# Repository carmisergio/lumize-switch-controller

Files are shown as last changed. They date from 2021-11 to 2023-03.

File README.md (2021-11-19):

# Lumize Switch Controller

A rack-mountable device for receiving input from physical wall switches and using it in a home automation situation

## Goal

When designing the home automation system for a reasonably sized attic, I came to the conclusion
that there aren't any good commercial solutions for reliably reading button input from switches mounted
in regular wall boxes. So I decided to design my own.

To avoid the complication (and waste of space) of having a network connected microcontroller in
each wall box, I chose to implement a solution based on a central device, with cables running to each button.
This poses the challenge of bringing upwards of four signals all the way from each corner of the floor
to a central location. The only cheap and easy to come by cable that has enough conductors is UTP cable,
usually used for ethernet networks. The cable is terminated as RJ45 male inside the wall box, and into a
patch panel at the central location.

## Switches

For my system, I wanted to use regular italian style wall switches, so I needed a way of interfacing
the RJ45 to some bare wire to be plugged into the buttons. This is done with a simple PCB i call the
"Switch Terminator Board", which exposes the connections as screw terminals.

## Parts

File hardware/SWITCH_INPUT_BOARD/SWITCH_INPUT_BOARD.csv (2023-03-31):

Source: | /home/sergio/projects/lumize-switch-controller/hardware/SWITCH_INPUT_BOARD/SWITCH_INPUT_BOARD.sch
Date: | Sun 13 Mar 2022 12:25:39 PM CET
Tool: | Eeschema (6.0.2)
Generator: | /usr/share/kicad/plugins/bom_csv_grouped_by_value_with_fp.py
Component Count: | 24
Ref | Qnty | Value | Cmp name | Footprint | Description | Vendor
C1, | 1 | 10uF | CP | Capacitor_THT:CP_Radial_D4.0mm_P1.50mm
D1, | 1 | LED | LED | LED_SMD:LED_0805_2012Metric | Light emitting diode
J1, | 1 | 4 Port RJ45: A00-432-262-450 | A00-432-262-450-A00-432-262-450 | A00-432-262-450:A00-432-262-450
J2, J3, J4, | 3 | IDC_02x04 | Conn_02x04_Odd_Even | Connector_IDC:IDC-Header_2x04_P2.54mm_Vertical | Generic connector, double row, 02x04, odd/even pin numbering scheme (row 1 odd numbers, row 2 even numbers), script generated (kicad-library-utils/schlib/autogen/connector/)
J5, | 1 | IDC_02x06 | Conn_02x06_Odd_Even | Connector_IDC:IDC-Header_2x06_P2.54mm_Vertical | Generic connector, double row, 02x06, odd/even pin numbering scheme (row 1 odd numbers, row 2 even numbers), script generated (kicad-library-utils/schlib/autogen/connector/)
JP1, | 1 | Jumper_4X | Jumper_4X | Connector_PinHeader_2.54mm:PinHeader_2x04_P2.54mm_Vertical
JP2, JP3, JP4, | 3 | Jumper_2X | Jumper_2X | Connector_PinHeader_2.54mm:PinHeader_2x02_P2.54mm_Vertical
R1, R2, | 2 | 4.7K | R | Resistor_THT:R_Axial_DIN0207_L6.3mm_D2.5mm_P10.16mm_Horizontal | Resistor
R3, | 1 | 220 | R | Resistor_THT:R_Axial_DIN0207_L6.3mm_D2.5mm_P10.16mm_Horizontal | Resistor
RN1, RN2, RN3, RN4, | 4 | 4x1K | R_Pack04 | Resistor_SMD:R_Array_Convex_4x1206 | 4 resistor network, parallel topology
RN5, RN6, RN7, RN8, RN9, | 5 | 4x10K | R_Pack04 | Resistor_SMD:R_Array_Convex_4x1206 | 4 resistor network, parallel topology
U1, | 1 | MCP23017_SO | MCP23017_SO | Package_SO:SOIC-28W_7.5x17.9mm_P1.27mm | 16-bit I/O expander, I2C, interrupts, w pull-ups, SOIC-28

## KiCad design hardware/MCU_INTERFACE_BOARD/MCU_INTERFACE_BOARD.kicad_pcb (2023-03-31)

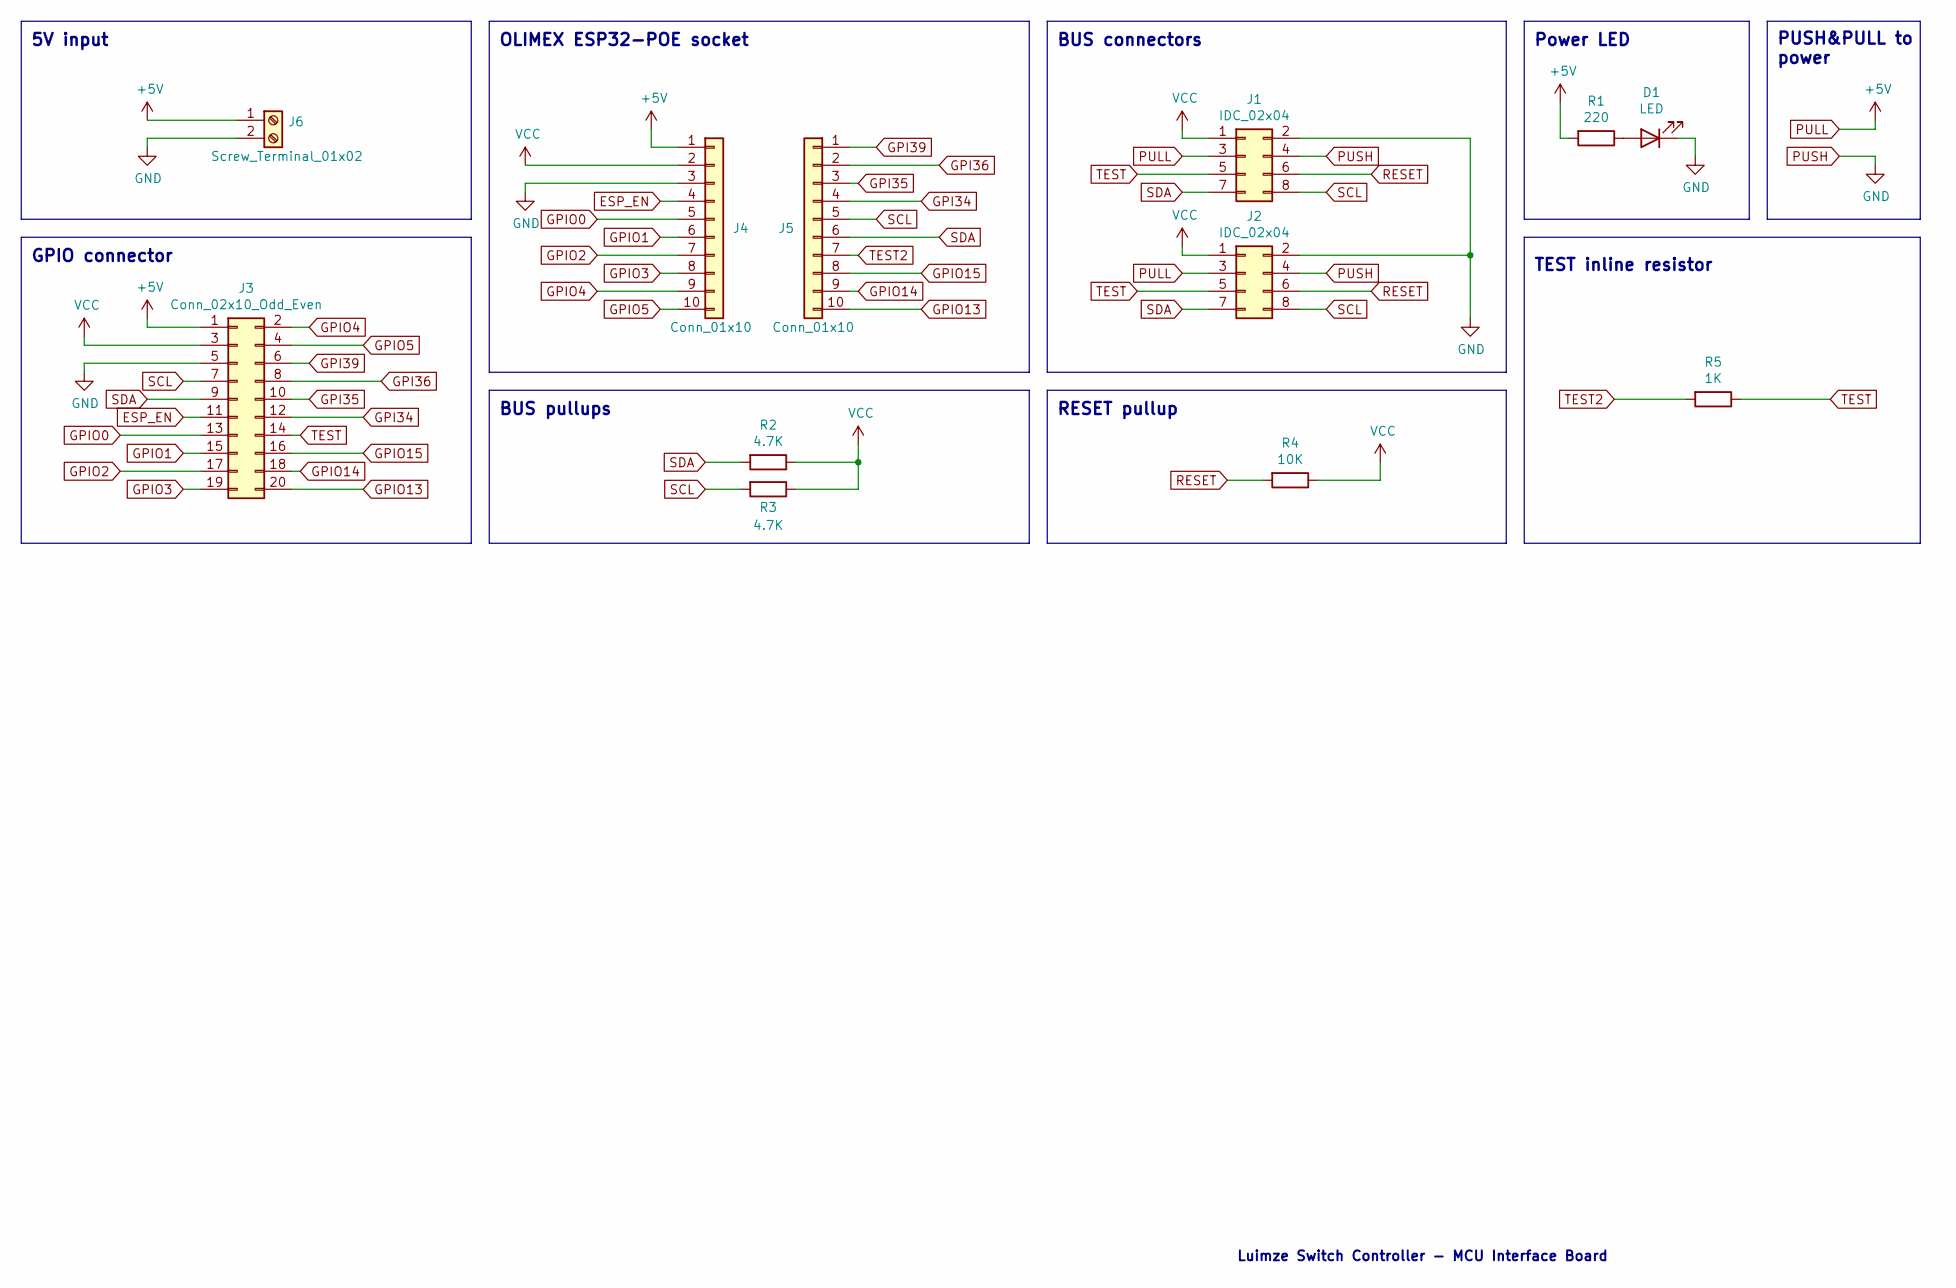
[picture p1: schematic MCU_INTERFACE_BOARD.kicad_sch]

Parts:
D1: LED; LED_0805_2012Metric
J1, J2: IDC_02x04; IDC-Header_2x04_P2.54mm_Vertical
J3: Conn_02x10_Odd_Even; IDC-Header_2x10_P2.54mm_Vertical
J4, J5: Conn_01x10; PinHeader_1x10_P2.54mm_Vertical
J6: Screw_Terminal_01x02; TerminalBlock_4Ucon_1x02_P3.50mm_Horizontal
R1: 220; R_Axial_DIN0207_L6.3mm_D2.5mm_P10.16mm_Horizontal
R2, R3: 4.7K; R_Axial_DIN0207_L6.3mm_D2.5mm_P10.16mm_Horizontal
R4: 10K; R_Axial_DIN0207_L6.3mm_D2.5mm_P10.16mm_Horizontal
R5: 1K; R_Axial_DIN0207_L6.3mm_D2.5mm_P10.16mm_Horizontal

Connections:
ESP_EN: J3.11, J4.4
GPI34: J3.12, J5.4
GPI35: J3.10, J5.3
GPI36: J3.8, J5.2
GPI39: J3.6, J5.1
GPIO0: J3.13, J4.5
GPIO1: J3.15, J4.6
GPIO2: J3.17, J4.7
GPIO3: J3.19, J4.8
GPIO4: J3.2, J4.9
GPIO5: J3.4, J4.10
GPIO13: J3.20, J5.10
GPIO14: J3.18, J5.9
GPIO15: J3.16, J5.8
unnamed: D1.2 (A), R1.1
PULL: J1.3, J2.3, J3.1, J4.1, J6.1, R1.2
PUSH: D1.1 (K), J1.2, J1.4, J2.2, J2.4, J3.5, J4.3, J6.2
RESET: J1.6, J2.6, R4.2
SCL: J1.8, J2.8, J3.7, J5.5, R3.2
SDA: J1.7, J2.7, J3.9, J5.6, R2.2
TEST: J1.5, J2.5, J3.14, R5.1
TEST2: J5.7, R5.2
VCC: J1.1, J2.1, J3.3, J4.2, R2.1, R3.1, R4.1

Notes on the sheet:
TEST inline resistor
BUS pullups
OLIMEX ESP32-POE socket
PUSH&PULL to power
GPIO connector
BUS connectors
Luimze Switch Controller - MCU Interface Board
5V input
Power LED
RESET pullup

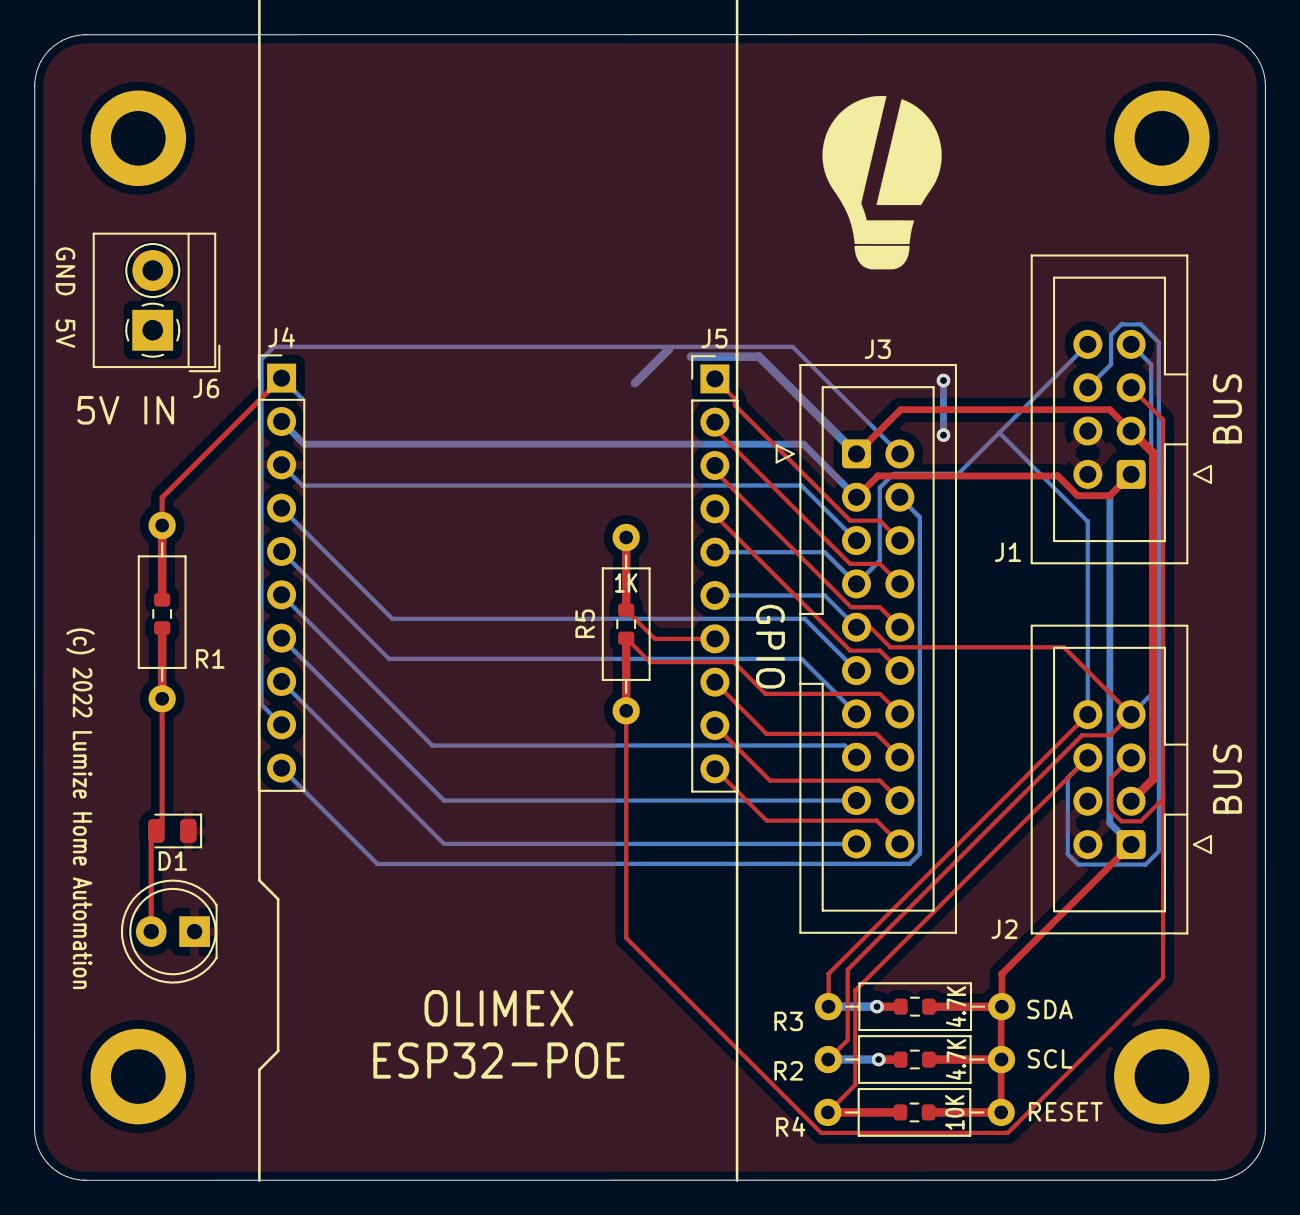
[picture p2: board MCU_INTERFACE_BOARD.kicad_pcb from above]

Board: 2 copper layers, 72.2 x 67.2 mm, 12 parts (0 on the bottom side), 23 nets.

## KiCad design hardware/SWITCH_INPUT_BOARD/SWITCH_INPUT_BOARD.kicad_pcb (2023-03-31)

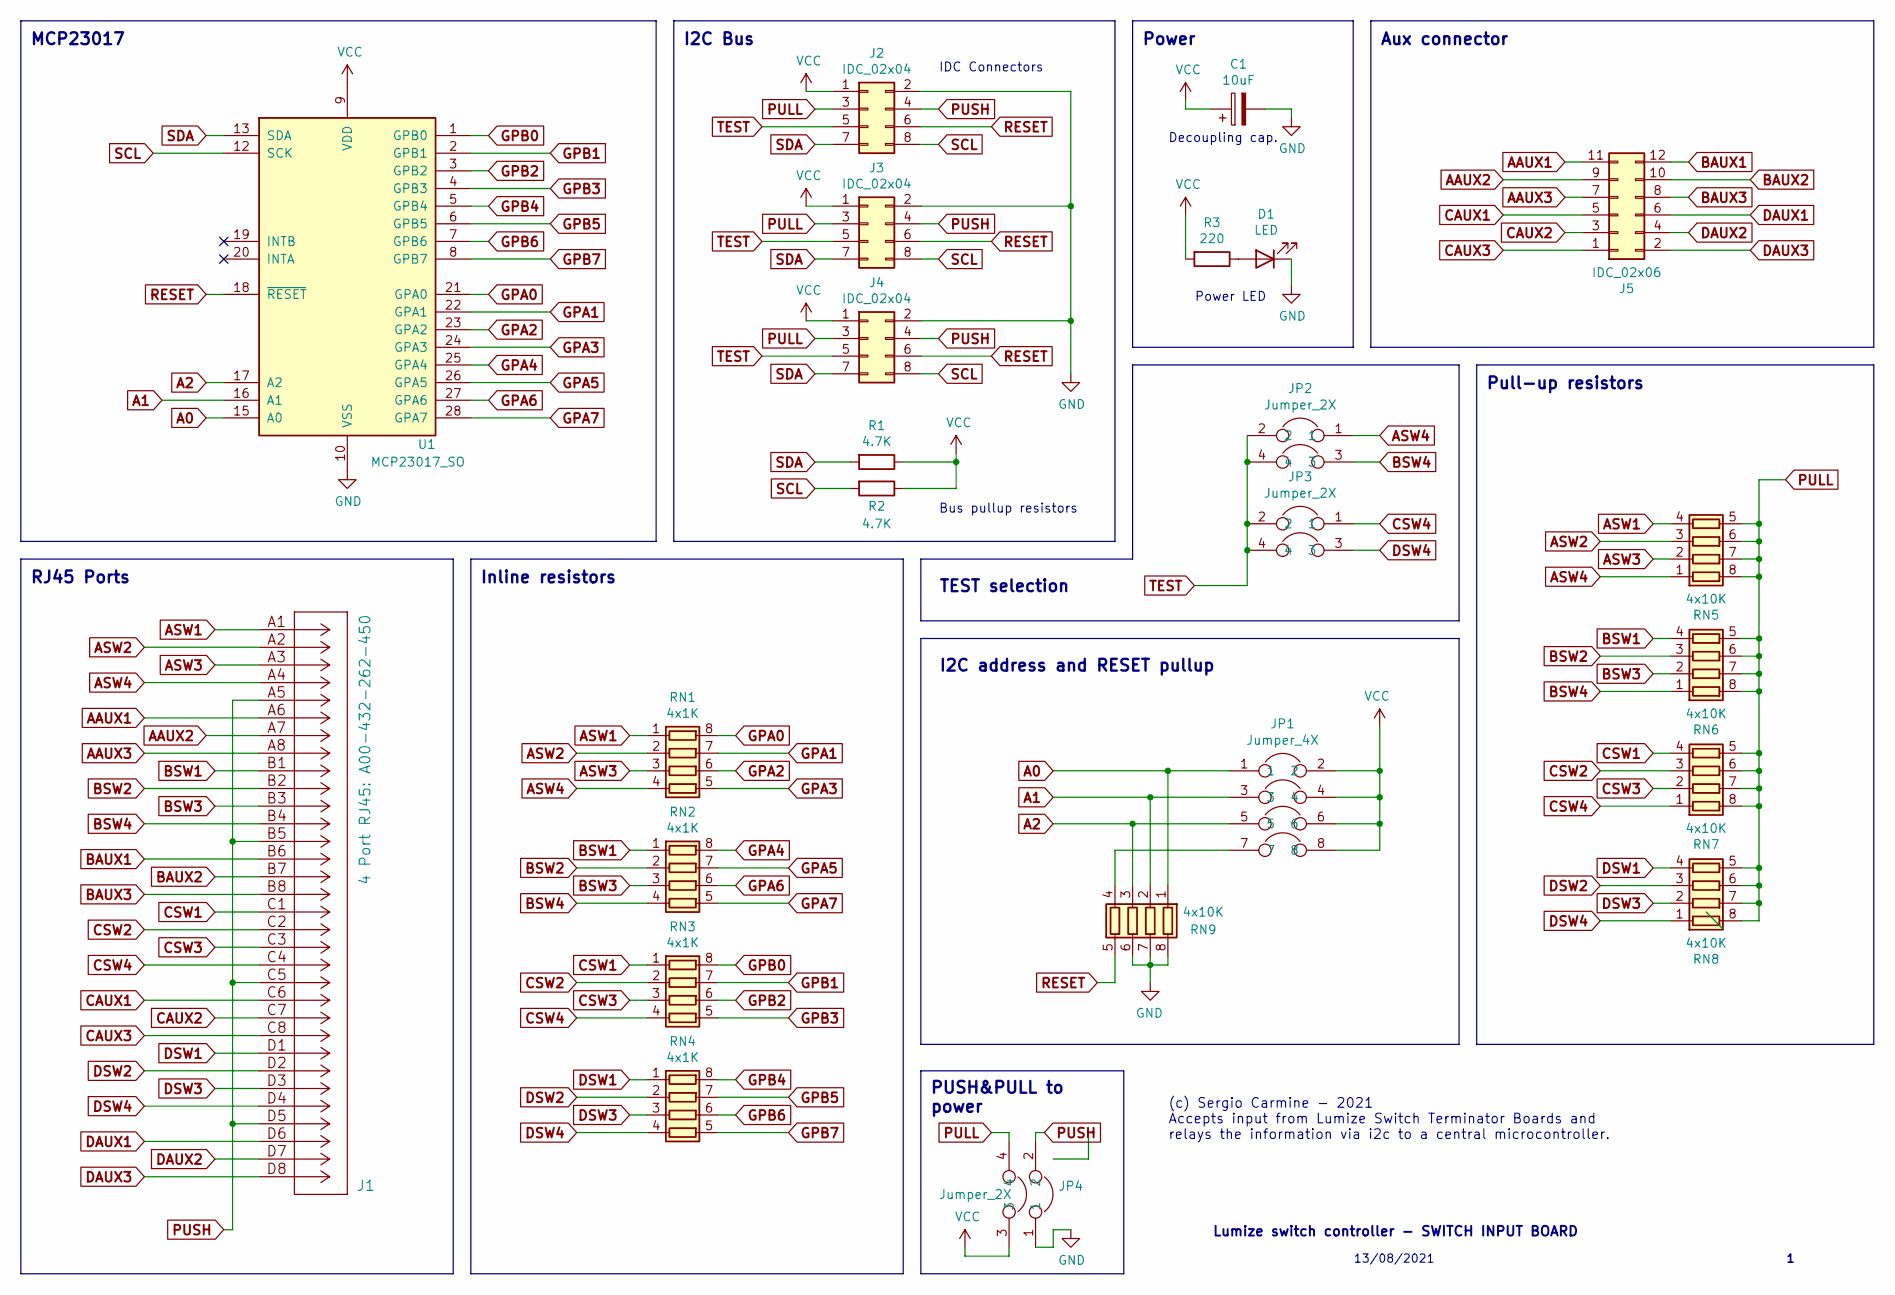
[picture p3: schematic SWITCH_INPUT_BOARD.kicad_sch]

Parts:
C1: 10uF; CP_Radial_D4.0mm_P1.50mm
D1: LED; LED_0805_2012Metric
J1: 4 Port RJ45: A00-432-262-450; A00-432-262-450
J2, J3, J4: IDC_02x04; IDC-Header_2x04_P2.54mm_Vertical
J5: IDC_02x06; IDC-Header_2x06_P2.54mm_Vertical
JP1: Jumper_4X; PinHeader_2x04_P2.54mm_Vertical
JP2, JP3, JP4: Jumper_2X; PinHeader_2x02_P2.54mm_Vertical
R1, R2: 4.7K; R_Axial_DIN0207_L6.3mm_D2.5mm_P10.16mm_Horizontal
R3: 220; R_Axial_DIN0207_L6.3mm_D2.5mm_P10.16mm_Horizontal
RN1, RN2, RN3, RN4: 4x1K; R_Array_Convex_4x1206
RN5, RN6, RN7, RN8, RN9: 4x10K; R_Array_Convex_4x1206
U1: MCP23017_SO; SOIC-28W_7.5x17.9mm_P1.27mm

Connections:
A0: JP1.1, RN9.1 (R1.1), U1.15 (A0)
A1: JP1.3, RN9.2 (R2.1), U1.16 (A1)
A2: JP1.5, RN9.3 (R3.1), U1.17 (A2)
AAUX1: J1.A6, J5.11
AAUX2: J1.A7, J5.9
AAUX3: J1.A8, J5.7
ASW1: J1.A1, RN1.1 (R1.1), RN5.4 (R4.1)
ASW2: J1.A2, RN1.2 (R2.1), RN5.3 (R3.1)
ASW3: J1.A3, RN1.3 (R3.1), RN5.2 (R2.1)
ASW4: J1.A4, JP2.1, RN1.4 (R4.1), RN5.1 (R1.1)
BAUX1: J1.B6, J5.12
BAUX2: J1.B7, J5.10
BAUX3: J1.B8, J5.8
BSW1: J1.B1, RN2.1 (R1.1), RN6.4 (R4.1)
BSW2: J1.B2, RN2.2 (R2.1), RN6.3 (R3.1)
BSW3: J1.B3, RN2.3 (R3.1), RN6.2 (R2.1)
BSW4: J1.B4, JP2.3, RN2.4 (R4.1), RN6.1 (R1.1)
CAUX1: J1.C6, J5.5
CAUX2: J1.C7, J5.3
CAUX3: J1.C8, J5.1
CSW1: J1.C1, RN3.1 (R1.1), RN7.4 (R4.1)
CSW2: J1.C2, RN3.2 (R2.1), RN7.3 (R3.1)
CSW3: J1.C3, RN3.3 (R3.1), RN7.2 (R2.1)
CSW4: J1.C4, JP3.1, RN3.4 (R4.1), RN7.1 (R1.1)
DAUX1: J1.D6, J5.6
DAUX2: J1.D7, J5.4
DAUX3: J1.D8, J5.2
DSW1: J1.D1, RN4.1 (R1.1), RN8.4 (R4.1)
DSW2: J1.D2, RN4.2 (R2.1), RN8.3 (R3.1)
DSW3: J1.D3, RN4.3 (R3.1), RN8.2 (R2.1)
DSW4: J1.D4, JP3.3, RN4.4 (R4.1), RN8.1 (R1.1)
GND: C1.2, D1.1 (K), J2.2, J3.2, J4.2, JP4.1, RN9.6 (R3.2), RN9.7 (R2.2), RN9.8 (R1.2), U1.10 (VSS); also elsewhere on the board
GPA0: RN1.8 (R1.2), U1.21 (GPA0)
GPA1: RN1.7 (R2.2), U1.22 (GPA1)
GPA2: RN1.6 (R3.2), U1.23 (GPA2)
GPA3: RN1.5 (R4.2), U1.24 (GPA3)
GPA4: RN2.8 (R1.2), U1.25 (GPA4)
GPA5: RN2.7 (R2.2), U1.26 (GPA5)
GPA6: RN2.6 (R3.2), U1.27 (GPA6)
GPA7: RN2.5 (R4.2), U1.28 (GPA7)
GPB0: RN3.8 (R1.2), U1.1 (GPB0)
GPB1: RN3.7 (R2.2), U1.2 (GPB1)
GPB2: RN3.6 (R3.2), U1.3 (GPB2)
GPB3: RN3.5 (R4.2), U1.4 (GPB3)
GPB4: RN4.8 (R1.2), U1.5 (GPB4)
GPB5: RN4.7 (R2.2), U1.6 (GPB5)
GPB6: RN4.6 (R3.2), U1.7 (GPB6)
GPB7: RN4.5 (R4.2), U1.8 (GPB7)
unnamed 48: D1.2 (A), R3.1; also elsewhere on the board
unnamed: JP1.7, RN9.4 (R4.1)
PULL: J2.3, J3.3, J4.3, JP4.4, RN5.5 (R4.2), RN5.6 (R3.2), RN5.7 (R2.2), RN5.8 (R1.2), RN6.5 (R4.2), RN6.6 (R3.2), RN6.7 (R2.2), RN6.8 (R1.2), RN7.5 (R4.2), RN7.6 (R3.2), RN7.7 (R2.2), RN7.8 (R1.2), RN8.5 (R4.2), RN8.6 (R3.2), RN8.7 (R2.2), RN8.8 (R1.2)
PUSH: J1.A5, J1.B5, J1.C5, J1.D5, J2.4, J3.4, J4.4, JP4.2
RESET: J2.6, J3.6, J4.6, RN9.5 (R4.2), U1.18 (~RESET)
SCL: J2.8, J3.8, J4.8, R2.2, U1.12 (SCK)
SDA: J2.7, J3.7, J4.7, R1.2, U1.13 (SDA)
TEST: J2.5, J3.5, J4.5, JP2.2, JP2.4, JP3.2, JP3.4
VCC: C1.1, J2.1, J3.1, J4.1, JP1.2, JP1.4, JP1.6, JP1.8, JP4.3, R1.1, R2.1, R3.2, U1.9 (VDD); also elsewhere on the board

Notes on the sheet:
Bus pullup resistors
Power LED
TEST selection
Pull-up resistors
I2C address and RESET pullup
Lumize switch controller - SWITCH INPUT BOARD
Power
MCP23017
Aux connector
IDC Connectors
13/08/2021
(c) Sergio Carmine - 2021 Accepts input from Lumize Switch Terminator Boards and relays the information via i2c to a central microcontroller.
Inline resistors
I2C Bus
RJ45 Ports
PUSH&PULL to power
Decoupling cap.

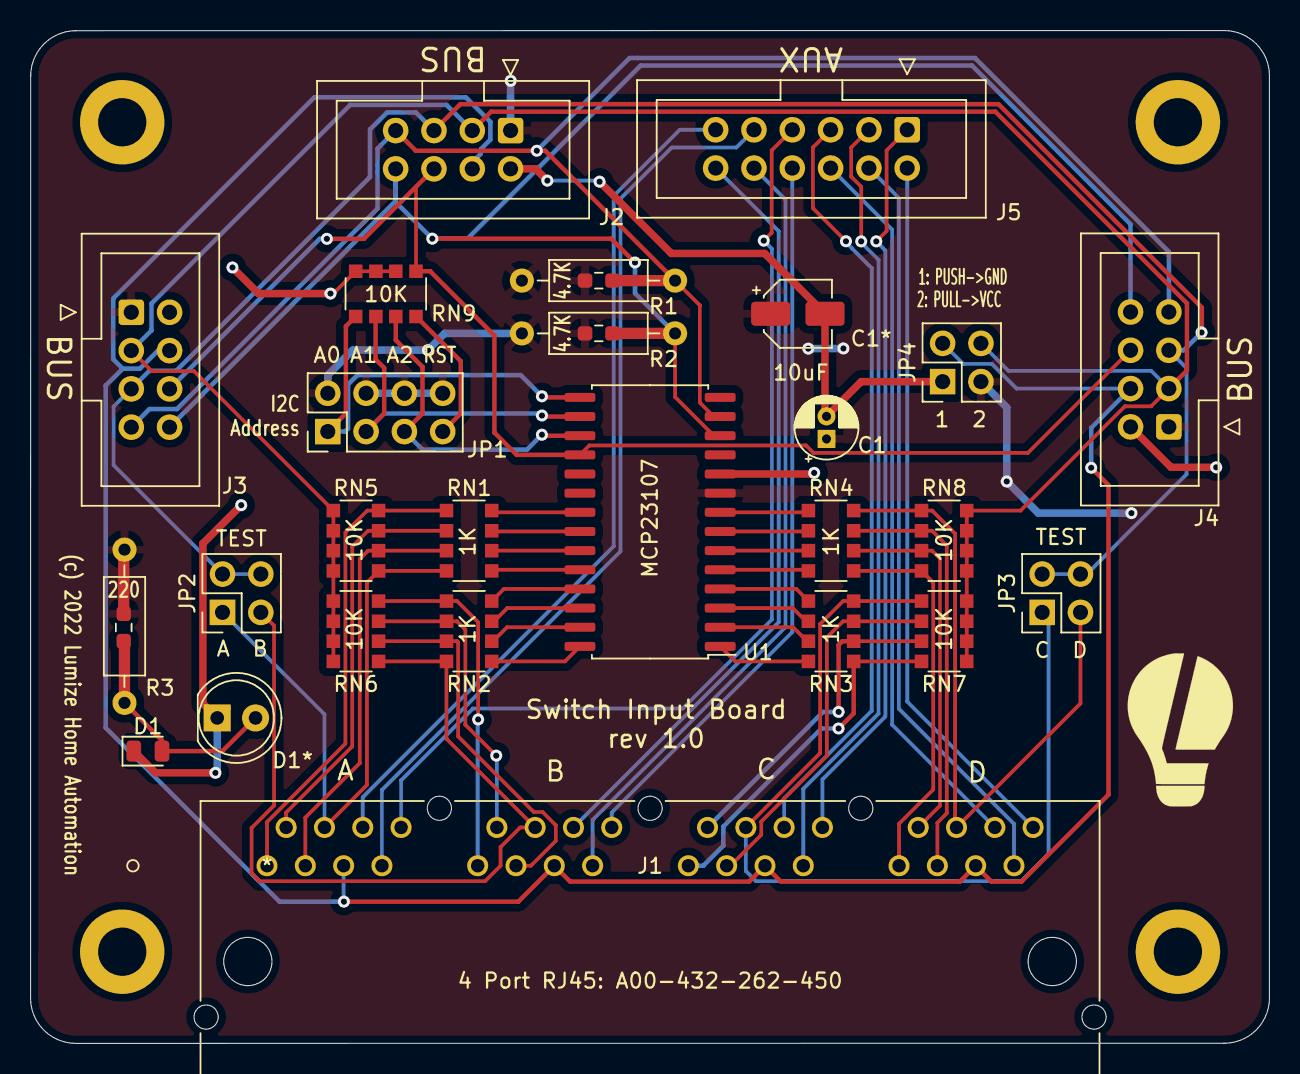
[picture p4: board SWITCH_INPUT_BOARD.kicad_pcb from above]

Board: 2 copper layers, 82.2 x 67.2 mm, 26 parts (0 on the bottom side), 57 nets.

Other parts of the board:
C1*: CP_Elec_4x5.8
D1*: LED_D5.0mm

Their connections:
GND: C1*.2, D1*.1; also elsewhere on the board
unnamed 48: D1*.2; also elsewhere on the board
VCC: C1*.1; also elsewhere on the board

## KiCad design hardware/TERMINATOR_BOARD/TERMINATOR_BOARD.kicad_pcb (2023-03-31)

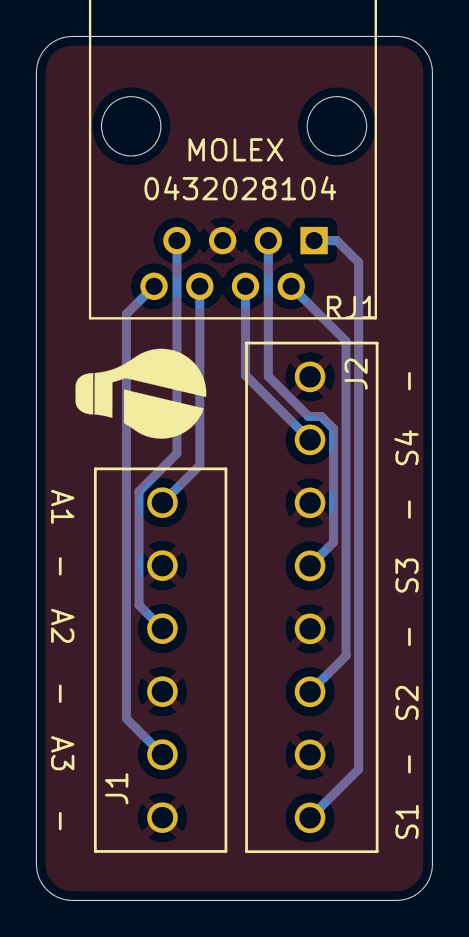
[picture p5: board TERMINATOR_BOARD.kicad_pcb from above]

Board: 2 copper layers, 22.0 x 48.0 mm, 3 parts (0 on the bottom side), 8 nets.

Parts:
J1: *; CONN8_1776275-8
J2: *; CONN6_1776275-6
RJ1: 0432028104; RJ45-TH_0432028104

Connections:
AUX1: J2.1, RJ1.6
AUX2: J2.3, RJ1.7
AUX3: J2.5, RJ1.8
GND: J1.2, J1.4, J1.6, J1.8, J2.2, J2.4, J2.6, RJ1.5
SW1: J1.1, RJ1.1
SW2: J1.3, RJ1.2
SW3: J1.5, RJ1.3
SW4: J1.7, RJ1.4

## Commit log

2021-11-19 Switch input board rev 1.0
    [SWITCH_INPUT_BOARD-B_Cu.gbr, SWITCH_INPUT_BOARD-B_Mask.gbr, SWITCH_INPUT_BOARD-B_Paste.gbr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]
2021-11-19 Organize folder structure
    [MCU_INTERFACE_BOARD.kicad_pcb, MCU_INTERFACE_BOARD.sch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]
2021-11-20 Add Terminator board
    [TERMINATOR_BOARD.kicad_pcb]
2023-03-31 Finish development
    [MCU_INTERFACE_BOARD-B_Cu.gbl, MCU_INTERFACE_BOARD-B_Mask.gbs, MCU_INTERFACE_BOARD-B_Paste.gbp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]

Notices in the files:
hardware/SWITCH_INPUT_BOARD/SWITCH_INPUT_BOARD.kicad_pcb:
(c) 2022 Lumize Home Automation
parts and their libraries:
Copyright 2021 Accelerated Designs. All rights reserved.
